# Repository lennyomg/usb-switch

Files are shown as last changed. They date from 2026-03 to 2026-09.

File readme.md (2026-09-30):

# USB Switch

This is a programmable USB 2.0 switch that connects one of two USB devices to a USB host at a time. It switches both data and power, fully disconnecting the inactive device. You can control it with a button or an external module.

This device is not a USB hub, neither logically nor internally. The switch is unidirectional: it cannot switch a single USB peripheral between two USB hosts.



### Technical details

The board is powered by an ATtiny1624, which controls FSUSB63UMX for switching USB data and TPS2066C for switching USB power. The board includes:
* 16 KB of storage, 2 KB of memory, and 256 bytes of EEPROM
* a 3.3 V regulator with a maximum current of 250 mA
* a USB-to-serial converter
* a single accessible LED
* two non-accessible LEDs for power status
* a built-in push button with an external 2.54 mm header
* a piezo speaker
* 2.54 mm header with 3.3 V, GND, and four GPIO/SPI pins

Check the [assembly guide](ASSEMBLY-GUIDE.md) and [dev notes](DEV-NOTES.md) for more details. Gerber files, BOM, STLs, and schematics can be found in [releases](https://github.com/lennyomg/usb-switch/releases/latest).

The `src` folder contains firmware examples built with PlatformIO.

### Application

This is primarily designed as a wired or wireless remote control for USB switching. For example, I added an external [433MHz radio garage door opener receiver](https://www.amazon.com/dp/B09P89RF8R) module and now I can switch between two wireless CarPlay adapters using my car HomeLink garage opener button.



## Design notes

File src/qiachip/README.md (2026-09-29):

This sample uses the built-in button or any of the four extension inputs to select the USB port. Each button press or rising signal on an extension input switches between port 1 and port 2. The selected port is saved to EEPROM and restored on startup. The buzzer plays a different tune for each selected port. The extension pins are connected to the [QIACHIP](https://www.amazon.com/dp/B09P89RF8R) RF module.

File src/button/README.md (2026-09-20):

This sample uses a momentary push button connected to the button input to select the USB port. Each press switches between port 1 and port 2. The selected port is saved to EEPROM and restored on startup. The sample also works with a wired push button.

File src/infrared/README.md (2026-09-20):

This sample uses an [Adafruit IR receiver](https://www.adafruit.com/product/5990) connected to PA1 to select a USB port with a generic remote. To learn a remote button, first select a port with the built-in button. Then hold the built-in button and press the button on the remote. The LED indicates IR reception. The selected port is saved to EEPROM and restored on startup.

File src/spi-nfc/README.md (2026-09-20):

This sample uses a PN532 NFC reader over SPI to select a USB port with a tag UID. Connect MOSI to PA1, MISO to PA2, SCK to PA3, and CS to PA4. To learn a tag, first select a port with the built-in button. Then hold the button and present the tag to the reader. The LED blinks three times when you release the button after learning. The selected port is saved to EEPROM and restored on startup.

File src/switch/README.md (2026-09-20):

This sample uses an external latching switch connected to the button input to select the USB port. A closed switch selects port 1; an open switch selects port 2.

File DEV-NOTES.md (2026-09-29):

# DEV NOTES

## Firmware

* Firmware source code is for Platform IO.

* Follow the assembly guide to install USB drivers. Update `upload_port` in `platformio.ini` accordingly.

* Set the switch to the ON-ON position to force the board into development mode and activate the built-in USB programmer.

* Firmware must guarantee that only one output is enabled at a time.

* `PIN_USB_PWR_1` and `PIN_USB_PWR_2` are intentionally swapped to compensate for the corresponding swap on the board.

* Some USB hosts may briefly cut off power when the board turns off both outputs. Therefore, save any persistent state before switching outputs.

* Each EEPROM cell has a limited write endurance (approximately 100,000 cycles), so depending on usage, consider rotating addresses used for stored data.

* On switching, disconnect data before disabling VBUS. When enabling a port, enable VBUS first and connect data after VBUS has stabilized. Keep the pre-connect powered interval below 100 ms.

* Set pins PA1, PA2, PA3, and PA4 to `INPUT_PULLUP` mode unless they are used by an external IC.

* The firmware must be configured for 10 MHz and internal oscillator.

## Board

* FSUSB63UMX is a 3:1 USB multiplexer. Outputs 1 and 2 are wired to USB ports and controlled by firmware. Output 3 is connected to CH340 programmer and selected by the slide switch.

* TPS2066C controls USB power switching.

* ATtiny controls data and power switching.

* Switched VBUS outputs are wired to green power-status LEDs. TPS2066C prevents OUT-to-IN current, but LEDs will be powered if voltage is applied to a USB output port.

* Logical data and power net numbers do not match physical port numbers because of the different pin order.

* The USB-C connection has 5.1 kΩ resistors and SMF5V0A TVS surge protection.

* USB input data lines cross each other on different layers because of FSUSB63UMX's pin order. The number of vias on each data line must match, and traces within each USB differential pair should be closely length-matched.

* Each USB input and output has a USBLC6. USBLC6 is a flow-through ESD protection device, meaning that pins 1-6 and 3-4 are connected internally. The board's custom USBLC6 footprints include jumpers that connect these pin pairs, although directly shorting each pair also works.

* Setting 218-2LPST slide switch to the ON-ON position forces FSUSB63UMX to activate CH340X UPDI programmer. The UPDI pin is reserved exclusively for programming and must not be reused as GPIO. It is connected to CH340X programming interface and exposed as a troubleshooting test point. Do not apply 12 V to this net, as doing so could damage CH340X.

* ATtiny controls a single red LED to indicate a user-defined state.

* ATtiny can be controlled by the active-low push button. The push button has a 2.54 mm pin header for connecting a wired external button. Because the wire may be long, a GSMF3.3A TVS diode, a current-limiting resistor, and an external pull-up are included to protect against noise and ESD. The two-pin 2.54 mm header is physically compatible with through-hole 2.00 mm and 2.50 mm JST connectors (confirmed).

* ATtiny can play a tune through a CPT-9019A-SMT-TR. It MUST be a piezoelectric transducer, NOT a magnetic buzzer. The selected transducer is compatible with `CUI_CPT-9019S-SMT` footprint (confirmed).

* 218-2LPST slide switch is compatible with Copal_CHS-02B footprint (confirmed).

* ATtiny pins PA1, PA2, PA3, and PA4 are connected to 2.54 mm headers to use as an SPI interface or GPIO.

* Two 47 µF 0805 capacitors per an output is a way to mitigate the recommended 120 µF (TPS2066C specs).

* The board has four layers: F.Cu for USB routing and SMD; In1.Cu for the GND plane; In2.Cu for power lines and the GND plane; and B.Cu for control lines.

* USB data trace dimensions target a 90 Ω differential impedance for the specified stackup: 0.25 mm width, 0.15 mm gap, and 0.75 mm clearance from the ground plane on the same layer.

* TPS channels should default to OFF during initial attachment. If the MCU immediately enables a channel, the upstream source will see both input and output capacitance. The TPS soft-start function might mitigate this, but it is better to avoid enabling a channel immediately.

* USB-C resistors must be 5.1 kΩ **±1%**.

* USB shields are connected to GND.

## Pre-order Validation

* Implementation notes above must not contradict themselves.

* Schematic and PCB should match the description.

* SPI header is correctly mapped to ATtiny's SPI hardware.

* Buzzer is connected to a PWM-capable pin.

* Final UPDI routing enables simple USB-to-ATtiny Arduino programming.

* Verify USB-C input TVS protection against the diode datasheet.

* Verify the external button TVS surge protection against the diode datasheet.

* USB-C routing must be valid for a USB-C peripheral device.

* Verify capacitor and resistor values and tolerances.

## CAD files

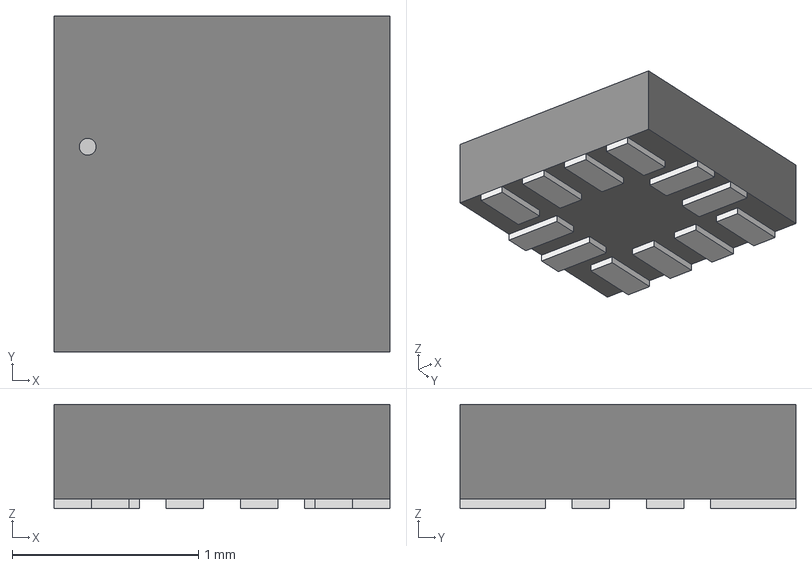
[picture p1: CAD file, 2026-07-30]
schematics/kvm/3d-models/UMLP12_1P8X1P8_ONS.step
1.80 x 1.80 x 0.561 mm

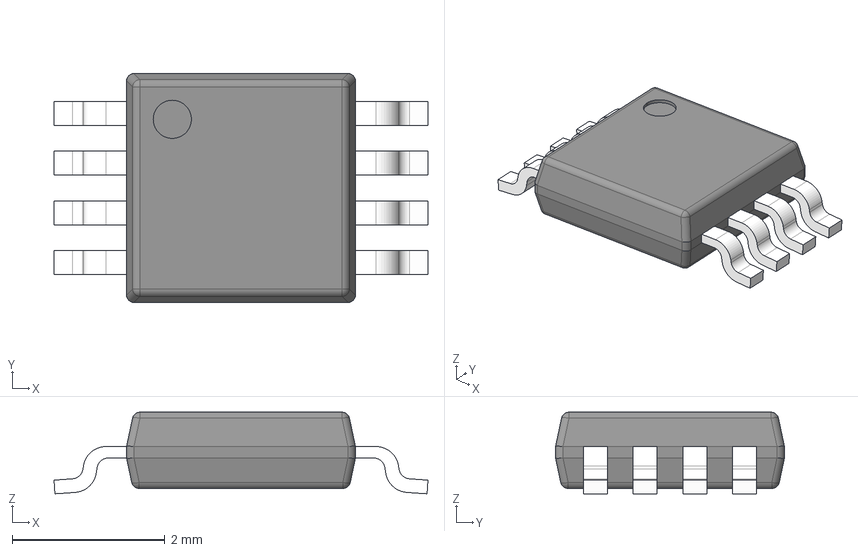
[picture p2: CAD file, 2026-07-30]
schematics/kvm/3d-models/DGN0008G.stp
4.90 x 3.00 x 1.07 mm
BODY-DGN0008G
LEAD-DGN0008G x 8
PIN1_DGN0008G
DAP_DGN0008G

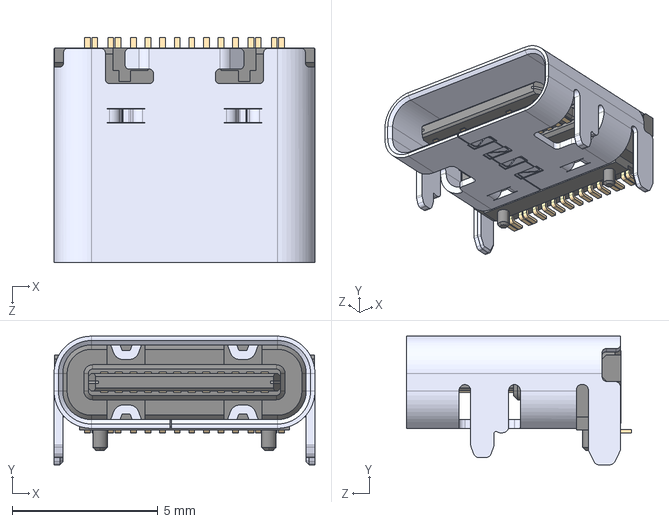
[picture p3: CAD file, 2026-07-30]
schematics/kvm/3d-models/USB4105-GF-A.STEP
8.94 x 4.41 x 7.71 mm

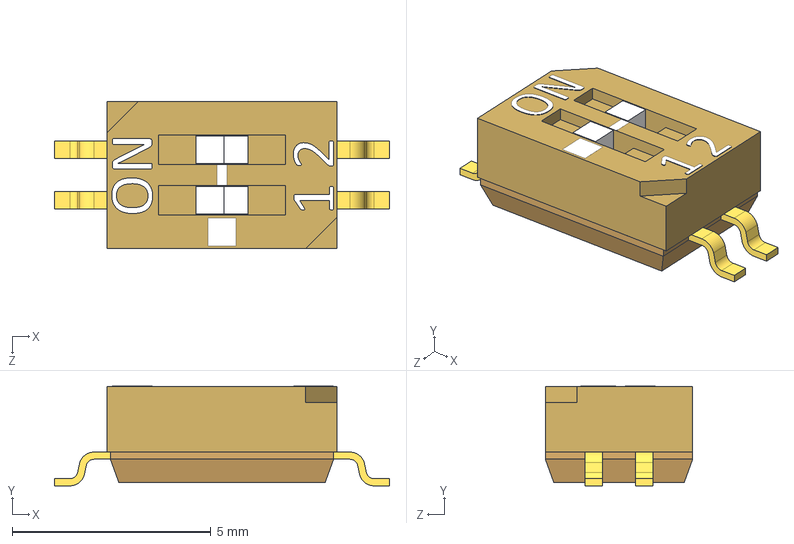
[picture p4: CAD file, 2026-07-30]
schematics/kvm/3d-models/218-2LP.STEP
8.43 x 2.51 x 3.71 mm
218 terminal lead frame x 2

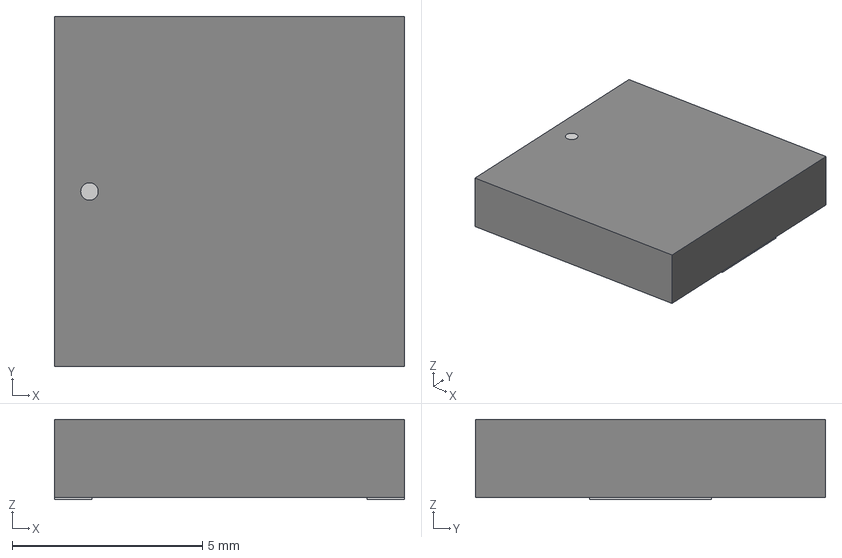
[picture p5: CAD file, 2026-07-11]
schematics/kvm/3d-models/CPT-9019A_CUD.step
9.19 x 9.19 x 2.11 mm

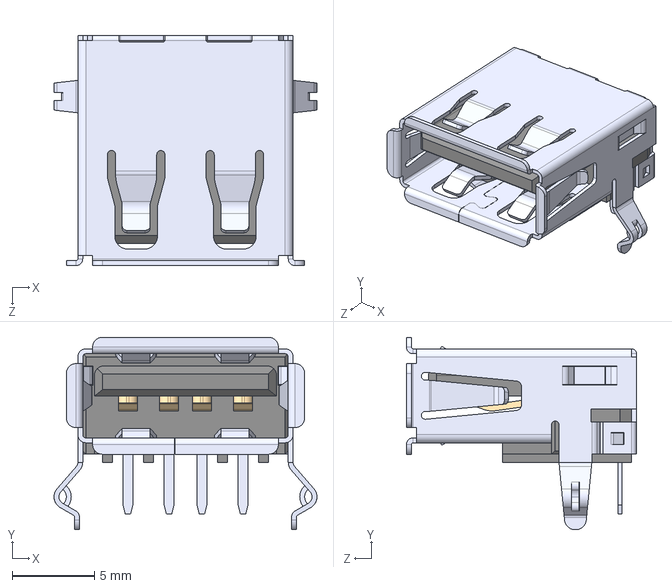
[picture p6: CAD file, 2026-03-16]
schematics/kvm/3d-models/SS-52100-001.STEP
16.0 x 11.7 x 14.0 mm

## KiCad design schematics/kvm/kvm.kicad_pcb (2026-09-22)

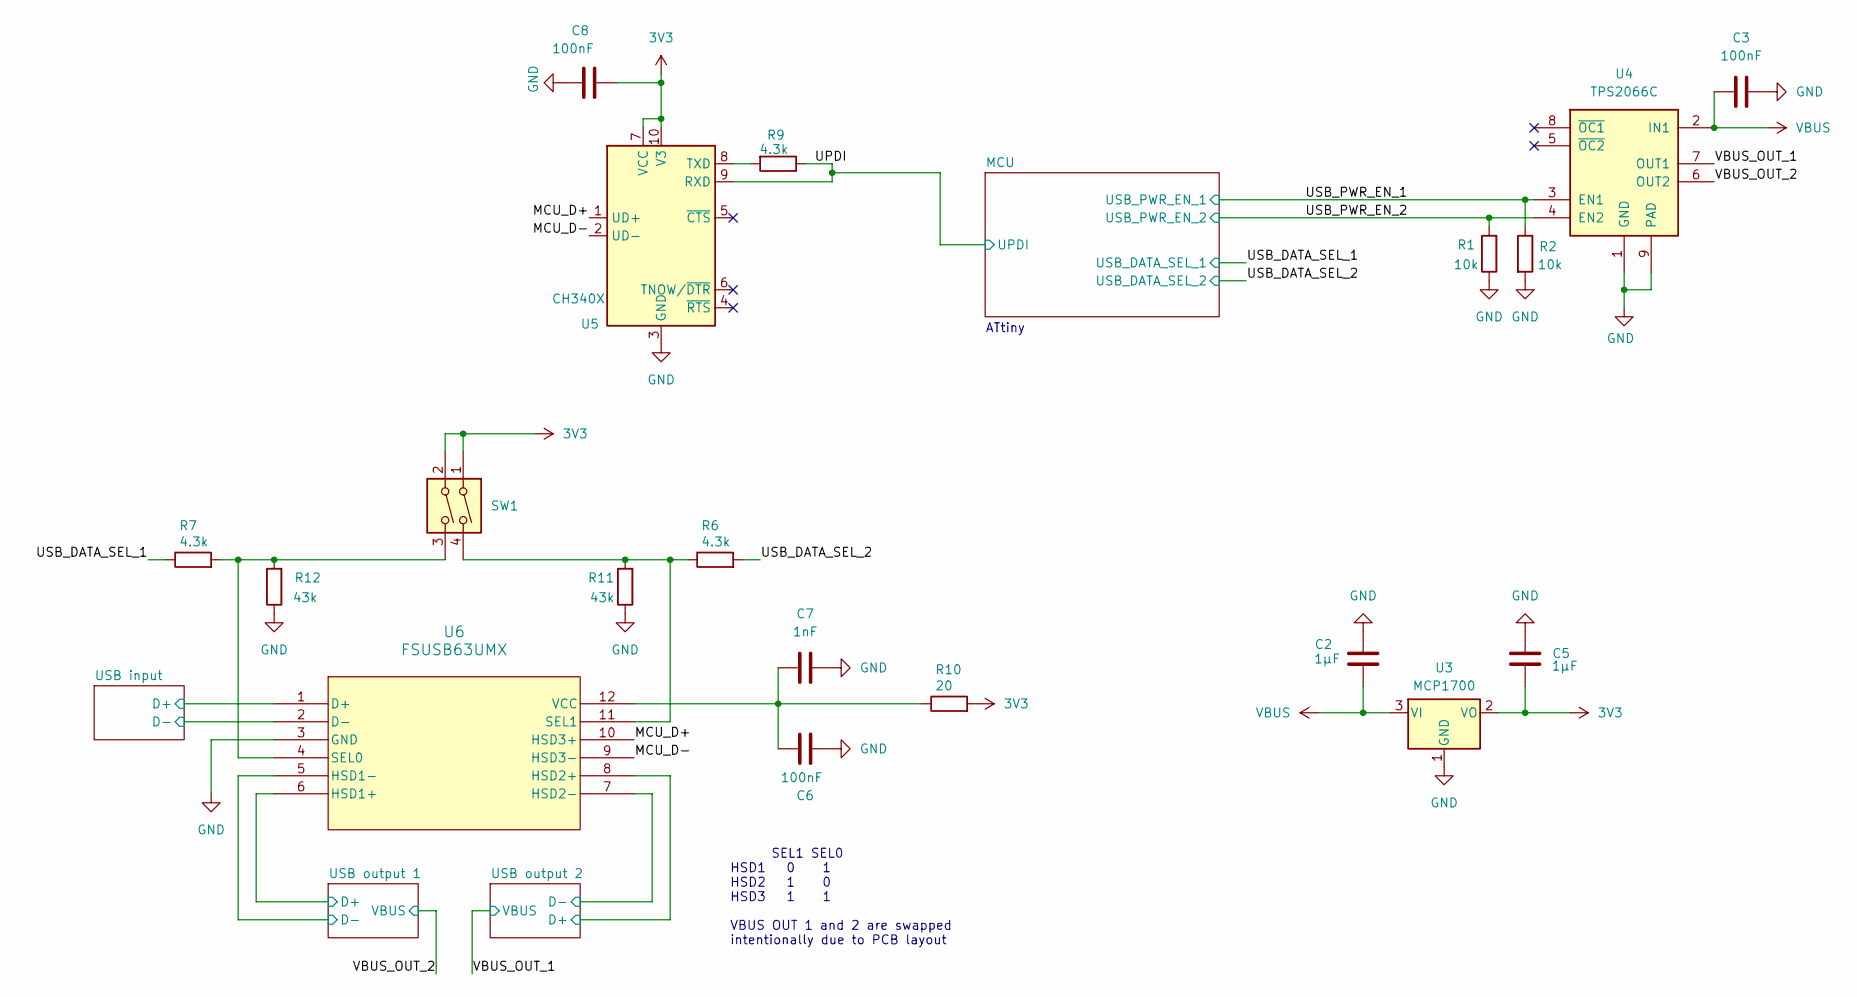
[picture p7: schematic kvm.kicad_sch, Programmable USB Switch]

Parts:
C2, C5: 1µF; C_0603_1608Metric
C3, C6, C8: 100nF; C_0603_1608Metric
C7: 1nF; C_0603_1608Metric
R1, R2: 10k; R_0603_1608Metric
R6, R7, R9: 4.3k; R_0603_1608Metric
R10: 20; R_0603_1608Metric
R11, R12: 43k; R_0603_1608Metric
SW1: SW_Slide_x2; SW_DIP_SPSTx02_Slide_Copal_CHS-02B_W7.62mm_P1.27mm; MPN 218-2LPST; DigiKey CT2182LPST-ND
U3: MCP1700; SOT-23; MPN MCP1700T-3302E/TT; DigiKey MCP1700T3302ETTCT-ND
U4: TPS2066C; HVSSOP-8-1EP_3x3mm_P0.65mm_EP1.57x1.89mm; MPN TPS2066CDGNR; DigiKey 296-39355-1-ND
U5: CH340X; MSOP-10_3x3mm_P0.5mm; MPN SMD IC CH340X; DigiKey 1188-SMDICCH340X-ND
U6: FSUSB63UMX; UMLP12_1P8X1P8_ONS_WIDE; MPN FSUSB63UMX; DigiKey FSUSB63UMXCT-ND

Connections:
3V3: C5.2, C8.1, R10.2, SW1.1, SW1.2, U3.2 (VO), U5.7 (VCC), U5.10 (V3); also elsewhere on the board
/MCU_D+: U5.1 (UD+), U6.10 (HSD3+)
/MCU_D-: U5.2 (UD-), U6.9 (HSD3-)
/UPDI: R9.1, U5.9 (RXD); also elsewhere on the board
/USB input/D+: U6.1 (D+); also elsewhere on the board
/USB input/D-: U6.2 (D-); also elsewhere on the board
/USB output 1/D+: U6.6 (HSD1+); also elsewhere on the board
/USB output 1/D-: U6.5 (HSD1-); also elsewhere on the board
/USB output 2/D+: U6.8 (HSD2+); also elsewhere on the board
/USB output 2/D-: U6.7 (HSD2-); also elsewhere on the board
/USB_DATA_SEL_1: R7.1; also elsewhere on the board
/USB_DATA_SEL_2: R6.2; also elsewhere on the board
/USB_PWR_EN_1: R2.1, U4.3 (EN1); also elsewhere on the board
/USB_PWR_EN_2: R1.2, U4.4 (EN2); also elsewhere on the board
/VBUS_OUT_1: U4.7 (OUT1); also elsewhere on the board
/VBUS_OUT_2: U4.6 (OUT2); also elsewhere on the board
GND: C2.2, C3.2, C5.1, C6.2, C7.2, C8.2, R1.1, R2.2, R11.1, R12.1, U3.1 (GND), U4.1 (GND), U4.9 (PAD), U5.3 (GND), U6.3 (GND); also elsewhere on the board
unnamed: R9.2, U5.8 (TXD)
unnamed: R7.2, R12.2, SW1.3, U6.4 (SEL0)
unnamed: R6.1, R11.2, SW1.4, U6.11 (SEL1)
unnamed: C6.1, C7.1, R10.1, U6.12 (VCC)
VBUS: C2.1, C3.1, U3.3 (VI), U4.2 (IN1); also elsewhere on the board

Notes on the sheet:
VBUS OUT 1 and 2 are swapped intentionally due to PCB layout
ATtiny
SEL1 SEL0 HSD1 0 1 HSD2 1 0 HSD3 1 1

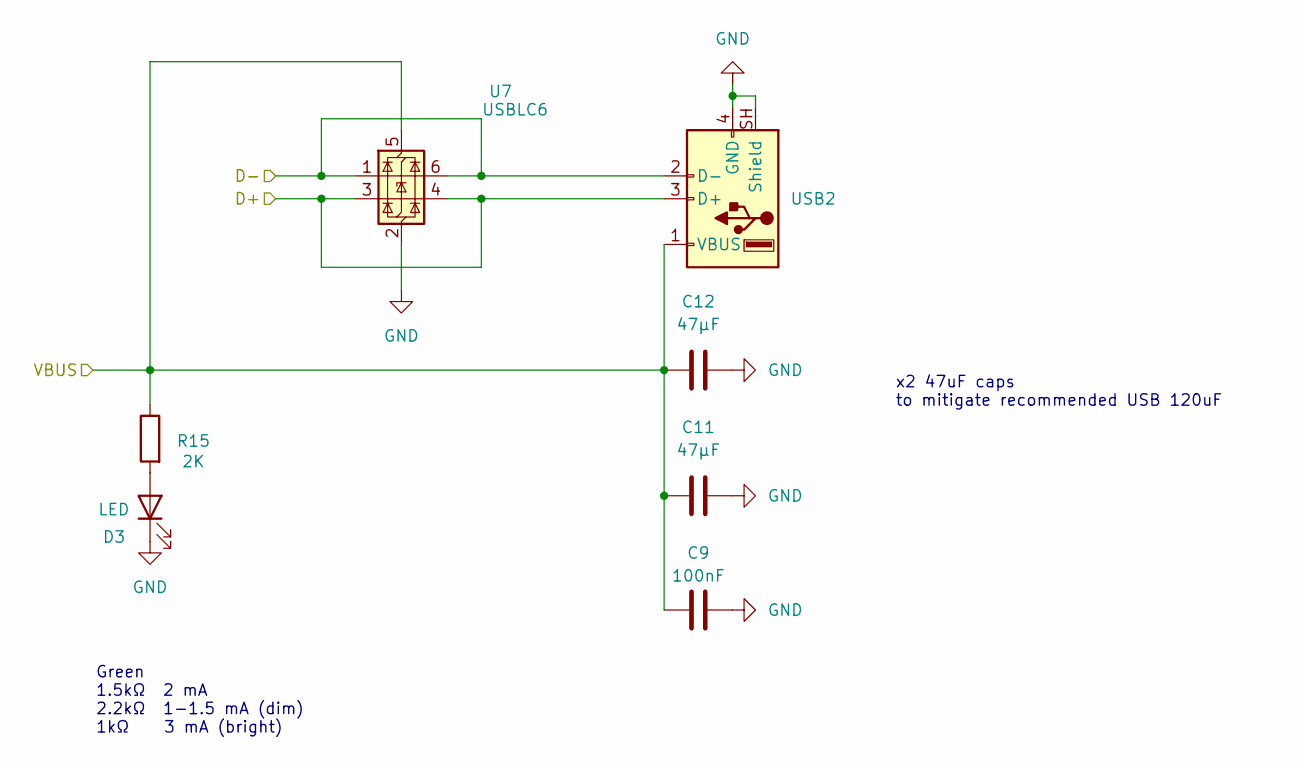
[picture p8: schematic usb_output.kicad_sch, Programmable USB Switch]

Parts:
C9: 100nF; C_0603_1608Metric
C11, C12: 47µF; C_0805_2012Metric
D3: LED; LED_0805_2012Metric; MPN 150080VS75000; DigiKey 732-4986-1-ND
R15: 2K; R_0603_1608Metric
U7: USBLC6; USBLC6-2SC6_SOT-23-6; MPN USBLC6-2SC6; DigiKey 497-5235-1-ND
USB2: USB; USB_A_Stewart_SS-52100-001_Horizontal; MPN SS-52100-001; DigiKey SS-52100-001

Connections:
/USB output 1/D+: U7.3 (I/O2), U7.4 (I/O2), USB2.3 (D+); also elsewhere on the board
/USB output 1/D-: U7.1 (I/O1), U7.6 (I/O1), USB2.2 (D-); also elsewhere on the board
/VBUS_OUT_2: C9.1, C11.1, C12.1, R15.1, U7.5 (VBUS), USB2.1 (VBUS); also elsewhere on the board
GND: C9.2, C11.2, C12.2, D3.1 (K), U7.2 (GND), USB2.4 (GND), USB2.SH (Shield); also elsewhere on the board
unnamed: D3.2 (A), R15.2

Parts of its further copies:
C10: 100nF; C_0603_1608Metric
C13, C14: 47µF; C_0805_2012Metric
D5: LED; LED_0805_2012Metric; MPN 150080VS75000; DigiKey 732-4986-1-ND
R16: 2K; R_0603_1608Metric
U8: USBLC6; USBLC6-2SC6_SOT-23-6; MPN USBLC6-2SC6; DigiKey 497-5235-1-ND
USB3: USB; USB_A_Stewart_SS-52100-001_Horizontal; MPN SS-52100-001; DigiKey SS-52100-001

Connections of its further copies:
/USB output 2/D+: U8.3 (I/O2), U8.4 (I/O2), USB3.3 (D+); also elsewhere on the board
/USB output 2/D-: U8.1 (I/O1), U8.6 (I/O1), USB3.2 (D-); also elsewhere on the board
/VBUS_OUT_1: C10.1, C13.1, C14.1, R16.1, U8.5 (VBUS), USB3.1 (VBUS); also elsewhere on the board
GND: C10.2, C13.2, C14.2, D5.1 (K), U8.2 (GND), USB3.4 (GND), USB3.SH (Shield); also elsewhere on the board
unnamed: D5.2 (A), R16.2

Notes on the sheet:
x2 47uF caps to mitigate recommended USB 120uF
Green 1.5kΩ 2 mA 2.2kΩ 1-1.5 mA (dim) 1kΩ 3 mA (bright)

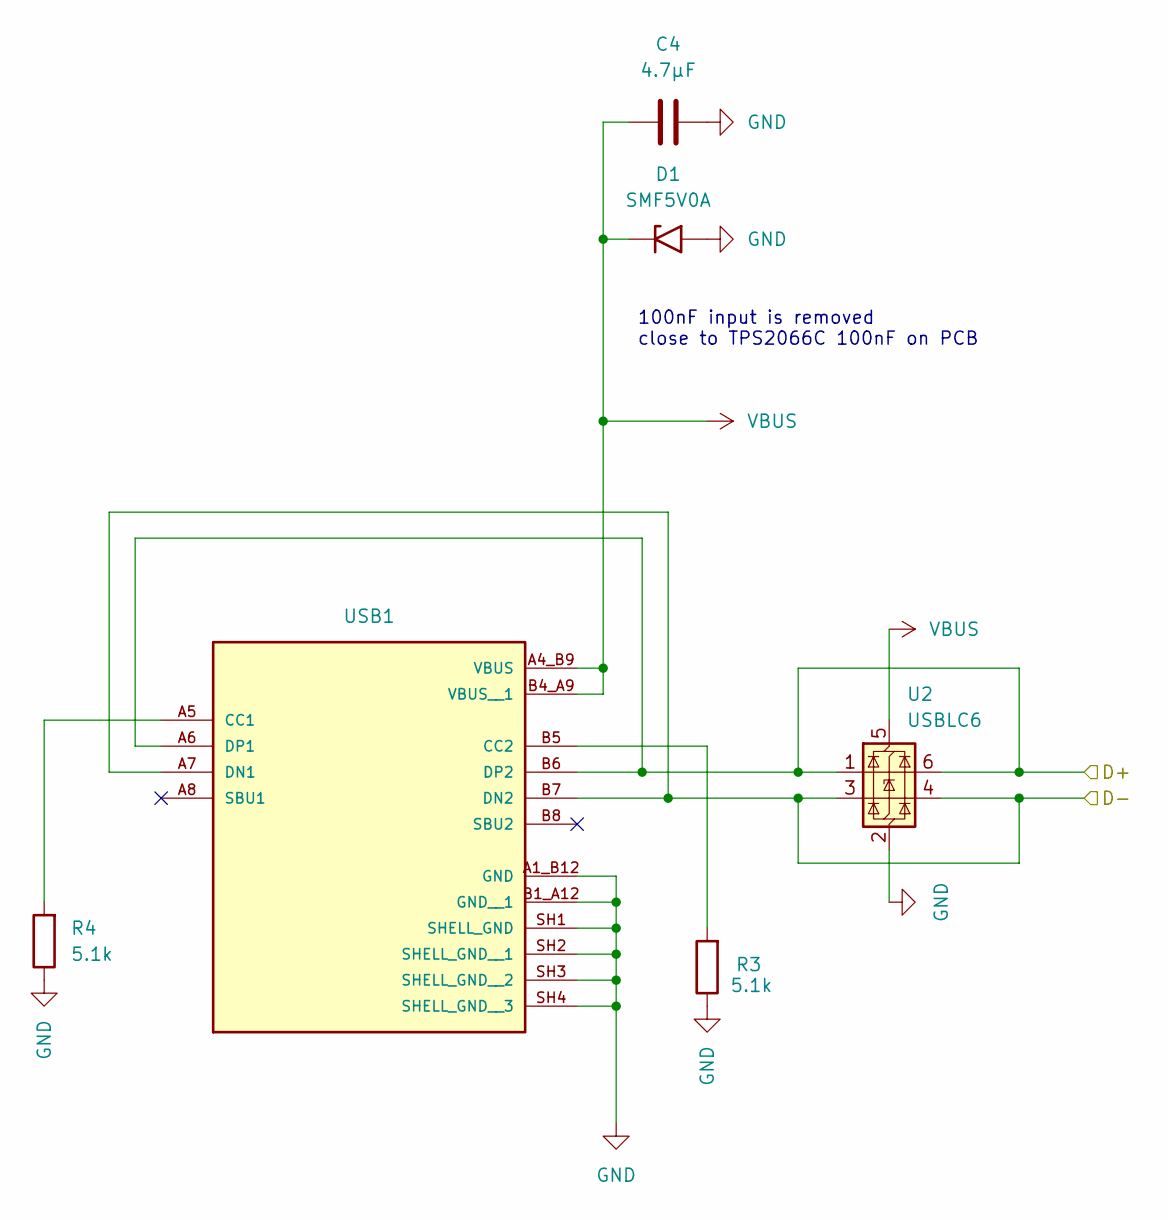
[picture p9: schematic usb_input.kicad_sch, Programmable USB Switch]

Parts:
C4: 4.7µF; C_0603_1608Metric
D1: SMF5V0A; D_SMF; MPN SMF5V0A-E3-08; DigiKey SMF5V0A-E3-08CT-ND
R3, R4: 5.1k; R_0603_1608Metric
U2: USBLC6; USBLC6-2SC6_SOT-23-6; MPN USBLC6-2SC6; DigiKey 497-5235-1-ND
USB1: USB_C_Receptacle_USB2.0_14P; GCT_USB4105-GF-A; MPN USB4105-GF-A; DigiKey 2073-USB4105-GF-ACT-ND

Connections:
/USB input/D+: U2.1 (I/O1), U2.6 (I/O1), USB1.A6 (DP1), USB1.B6 (DP2); also elsewhere on the board
/USB input/D-: U2.3 (I/O2), U2.4 (I/O2), USB1.A7 (DN1), USB1.B7 (DN2); also elsewhere on the board
GND: C4.2, D1.2 (A2), R3.1, R4.1, U2.2 (GND), USB1.A1_B12 (GND), USB1.B1_A12 (GND__1), USB1.SH1 (SHELL_GND), USB1.SH2 (SHELL_GND__1), USB1.SH3 (SHELL_GND__2), USB1.SH4 (SHELL_GND__3); also elsewhere on the board
unnamed: R4.2, USB1.A5 (CC1)
unnamed: R3.2, USB1.B5 (CC2)
VBUS: C4.1, D1.1 (A1), U2.5 (VBUS), USB1.A4_B9 (VBUS), USB1.B4_A9 (VBUS__1); also elsewhere on the board

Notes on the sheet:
100nF input is removed close to TPS2066C 100nF on PCB

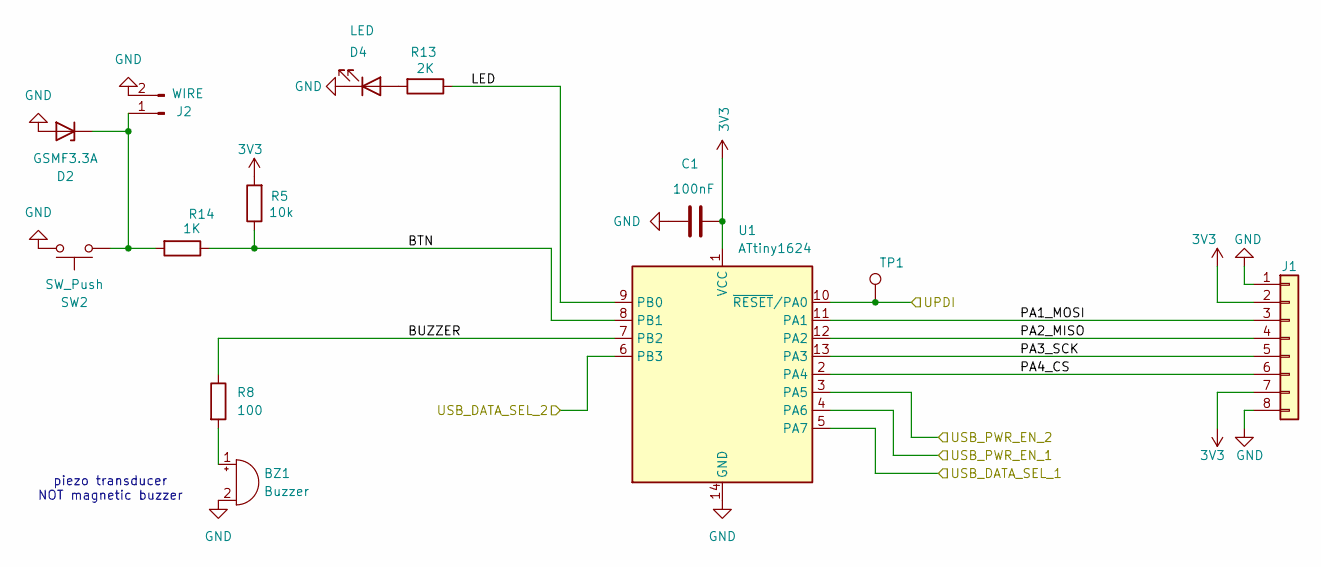
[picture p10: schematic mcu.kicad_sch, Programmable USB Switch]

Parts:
BZ1: Buzzer; Buzzer_CUI_CPT-9019S-SMT; MPN CPT-9019A-SMT-TR; DigiKey 2223-CPT-9019A-SMT-TRCT-ND
C1: 100nF; C_0603_1608Metric
D2: GSMF3.3A; D_SOD-123FL_GSMF3-3A; MPN GSMF3.3A; DigiKey 4786-GSMF3.3ACT-ND
D4: LED; LED_0805_2012Metric; MPN 150080SS75000; DigiKey 732-4985-1-ND
J1: EXT; PinHeader_1x08_P2.54mm_Vertical
J2: WIRE; PinHeader_1x02_P2.54mm_Vertical
R5: 10k; R_0603_1608Metric
R8: 100; R_0603_1608Metric
R13: 2K; R_0603_1608Metric
R14: 1K; R_0603_1608Metric
SW2: SW_Push; SW_PUSH_6mm; MPN TS02-66-43-BK-160-LCR-D; DigiKey 2223-TS02-66-43-BK-160-LCR-D-ND
TP1: TestPoint; TestPoint_Pad_D1.5mm
U1: ATtiny1624; TSSOP-14_4.4x5mm_P0.65mm; MPN ATTINY1624-XUR; DigiKey 150-ATTINY1624-XURCT-ND

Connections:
3V3: C1.1, J1.2, J1.7, R5.2, U1.1 (VCC); also elsewhere on the board
/MCU/BTN: R5.1, R14.1, U1.8 (PB1)
/MCU/BUZZER: R8.1, U1.7 (PB2)
/MCU/LED: R13.1, U1.9 (PB0)
/MCU/PA1_MOSI: J1.3, U1.11 (PA1)
/MCU/PA2_MISO: J1.4, U1.12 (PA2)
/MCU/PA3_SCK: J1.5, U1.13 (PA3)
/MCU/PA4_CS: J1.6, U1.2 (PA4)
/UPDI: TP1.1 (1_1), U1.10 (~RESET/PA0); also elsewhere on the board
/USB_DATA_SEL_1: U1.5 (PA7); also elsewhere on the board
/USB_DATA_SEL_2: U1.6 (PB3); also elsewhere on the board
/USB_PWR_EN_1: U1.4 (PA6); also elsewhere on the board
/USB_PWR_EN_2: U1.3 (PA5); also elsewhere on the board
GND: BZ1.2 (-), C1.2, D2.2 (A), D4.1 (K), J1.1, J1.8, J2.2, SW2.2, U1.14 (GND); also elsewhere on the board
unnamed: BZ1.1 (+), R8.2
unnamed: D2.1 (K), J2.1, R14.2, SW2.1
unnamed: D4.2 (A), R13.2

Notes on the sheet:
piezo transducer NOT magnetic buzzer

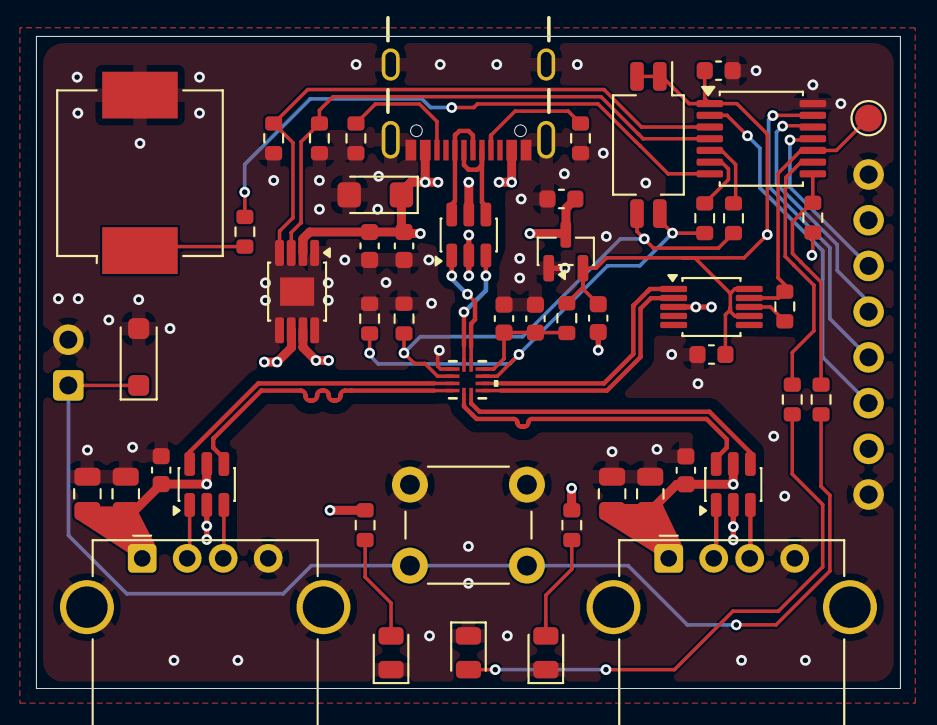
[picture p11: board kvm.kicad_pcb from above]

Board: 4 copper layers, 48.0 x 36.2 mm, 52 parts (0 on the bottom side), 36 nets.

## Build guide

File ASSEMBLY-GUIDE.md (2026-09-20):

# Assembly guide

This is how to build, print, flash, and assemble this project. Check [releases](https://github.com/lennyomg/usb-switch/releases/latest) for manufacturing files.

## Board

Order a 4-layer PCB using the attached Gerber and drill files. Add a stencil to your order if possible. A rework station or hot plate is required to assemble the board, the USB mux is too small for a soldering iron.

The BOM contains manufacturer part numbers for DigiKey and LCSC. When ordering parts, pay attention to the specified tolerances (5.1 kΩ **±1%** resistors, for example).

### Enclosure

[Project in OnShape](https://cad.onshape.com/documents/5c8a980f8b2f233ca52af940/w/8f21e194ecc758069b76b15f/e/5b9ec8950a9bfdcf718e2e62).

The project has configuration parameters to increase the box width and height. It also has options to hide the button, speaker holes, and LEDs.

Print in regular PETG with a **0.2 mm** nozzle, preferably in a dark color. Cut small pieces of translucent PETG filament and insert them into the LED holes to make light diffusers. Screw the top and bottom parts together with four M2 screws.

## USB serial driver

The board includes CH340 USB-to-serial converter for programming. Set the onboard switch to the **ON-ON** position, disconnect all devices from the USB-A outputs, and connect the board's USB-C input to the computer.

##### macOS

Install the WCH driver with Homebrew:

```sh
brew install --cask wch-ch34x-usb-serial-driver
```

Follow any prompt to allow the driver in **System Settings > Privacy & Security**. Restart the computer if requested, reconnect the board, and run `ls /dev/cu.*` again. Look for a device such as `/dev/cu.wchusbserial1420` or `/dev/cu.usbserial-1420`.

##### Windows

Windows may install the CH340 driver automatically. To find the port, open **Device Manager > Ports (COM & LPT)**, look for **USB-SERIAL CH340**, and note its port, such as `COM7`.

If the device is missing or appears with a warning icon, download and install the official [WCH CH340/CH341 Windows driver](https://www.wch-ic.com/downloads/CH341SER_ZIP.html). 

## Install AVRDUDE

Use AVRDUDE 8 or newer for flashing the device.

##### macOS

Install AVRDUDE with Homebrew:

```sh
brew install avrdude
```

##### Windows

1. Download the latest Windows x64 ZIP archive from the official [AVRDUDE releases page](https://github.com/avrdudes/avrdude/releases/latest).
2. Extract the archive to a permanent folder.
3. Add that folder to `PATH`, or open PowerShell in the extracted folder and run `avrdude.exe` from there.

## Flash the board

Replace the example serial port and `file.hex` with the actual port and firmware file path.

##### macOS

```sh
avrdude -c serialupdi -p t1624 -P /dev/cu.wchusbserial1420 -b 115200 -U flash:w:file.hex:i
```

##### Windows

```powershell
.\avrdude.exe -c serialupdi -p t1624 -P COM7 -b 115200 -U flash:w:file.hex:i
```

Wait for AVRDUDE to report that verification succeeded. Disconnect the USB-C cable, set the onboard switch to the **1-2** position, and reconnect the board.

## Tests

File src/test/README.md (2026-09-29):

This firmware is used to test an assembled board. On startup, the LED flashes five times and the buzzer plays three tones. Extension input 1 turns both USB ports off, input 2 selects port 1, and input 3 selects port 2. The built-in button or extension input 4 switches between ports 1 and 2. Each action plays a tone, and the LED remains on while both ports are off.

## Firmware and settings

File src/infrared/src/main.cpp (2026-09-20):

// Copyright (c) 2026 Leonid R.
// SPDX-License-Identifier: MIT

#include <Arduino.h>
#include <Bounce2.h>
#include <EEPROM.h>
#define IR_USE_AVR_TIMER_A
#include <IRremote.hpp>

constexpr auto PIN_USB_PWR_1 = PIN_PA6;
constexpr auto PIN_USB_PWR_2 = PIN_PA5;
constexpr auto PIN_USB_DAT_1 = PIN_PB3;
constexpr auto PIN_USB_DAT_2 = PIN_PA7;
constexpr auto PIN_BUZZER = PIN_PB2;
constexpr auto PIN_BTN = PIN_PB1;
constexpr auto PIN_LED = PIN_PB0;
constexpr auto PIN_IR = PIN_PA1;

constexpr uint8_t STATE_ADDR = 2;
constexpr uint8_t STATE_HEADER_1 = 0x55;
constexpr uint8_t STATE_HEADER_2 = 0xFF;
constexpr uint8_t STATE_1_LENGTH_ADDR = 3;
constexpr uint8_t STATE_2_LENGTH_ADDR = 4;
constexpr uint8_t STATE_1_DATA_ADDR = 10;
constexpr uint8_t STATE_2_DATA_ADDR = 100;

uint8_t state;
Bounce2::Button btn;
uint8_t data[4];
uint8_t dataLength;
bool learning = false;

void switchModeOff();
void switchMode1();
void switchMode2();
void ledOn();
void ledOff();
void readState();
void writeState();
bool readData();
bool matchData(uint8_t lengthAddr, uint8_t dataAddr);
void learnData(uint8_t learnAddr, uint8_t dataAddr);

void setup()
{
    pinMode(PIN_LED, OUTPUT);
    ledOff();

    switchModeOff();
    pinMode(PIN_USB_PWR_1, OUTPUT);
    pinMode(PIN_USB_PWR_2, OUTPUT);
    pinMode(PIN_USB_DAT_1, OUTPUT);
    pinMode(PIN_USB_DAT_2, OUTPUT);

    pinMode(PIN_BUZZER, OUTPUT);
    digitalWrite(PIN_BUZZER, LOW);

    pinMode(PIN_PA2, INPUT_PULLUP);
    pinMode(PIN_PA3, INPUT_PULLUP);
    pinMode(PIN_PA4, INPUT_PULLUP);

    btn.attach(PIN_BTN, INPUT_PULLUP);
    btn.interval(5);
    btn.setPressedState(LOW);

    if (EEPROM.read(0) != STATE_HEADER_1 || EEPROM.read(1) != STATE_HEADER_2)
    {
        EEPROM.write(0, STATE_HEADER_1);
        EEPROM.write(1, STATE_HEADER_2);
        EEPROM.write(STATE_ADDR, 1);
        for (auto addr = 3; addr < EEPROM.length(); addr++)
            EEPROM.write(addr, 0);
    }

    readState();
    switch (state)
    {
    case 1:
        switchMode1();
        break;
    case 2:
        switchMode2();
        break;
    }

    IrReceiver.begin(PIN_IR, ENABLE_LED_FEEDBACK, PIN_LED);
}

void loop()
{
    auto needSwitch = false;
    btn.update();

    if (IrReceiver.decode())
    {
        if (readData())
        {
            if (btn.isPressed() && !learning)
            {
                learning = true;
                switch (state)
                {
                case 1:
                    learnData(STATE_1_LENGTH_ADDR, STATE_1_DATA_ADDR);
                    break;
                case 2:
                    learnData(STATE_2_LENGTH_ADDR, STATE_2_DATA_ADDR);
                    break;
                }
            }
            else
            {
                if (matchData(STATE_1_LENGTH_ADDR, STATE_1_DATA_ADDR))
                {
                    if (state != 1)
                        needSwitch = true;
                }
                else if (matchData(STATE_2_LENGTH_ADDR, STATE_2_DATA_ADDR))
                {
                    if (state != 2)
                        needSwitch = true;
                }
            }
        }

        IrReceiver.resume();
    }

    if (btn.released())
    {
        if (!learning)
        {
            needSwitch = true;
        }
        else
        {
            learning = false;
        }
    }

    if (needSwitch)
    {
        switch (state)
        {
        case 2:
            state = 1;
            writeState();
            switchMode1();
            break;
        default:
            state = 2;
            writeState();
            switchMode2();
            break;
        }
    }
}

void switchModeOff()
{
    digitalWrite(PIN_USB_DAT_1, LOW);
    digitalWrite(PIN_USB_DAT_2, LOW);
    digitalWrite(PIN_USB_PWR_1, LOW);
    digitalWrite(PIN_USB_PWR_2, LOW);
}

void switchMode1()
{
    switchModeOff();
    delay(200);

    digitalWrite(PIN_USB_PWR_1, HIGH);
    delay(20);
    digitalWrite(PIN_USB_DAT_1, HIGH);
}

void switchMode2()
{
    switchModeOff();
    delay(200);

    digitalWrite(PIN_USB_PWR_2, HIGH);
    delay(20);
    digitalWrite(PIN_USB_DAT_2, HIGH);
}

void readState()
{
    state = EEPROM.read(STATE_ADDR);
}

void writeState()
{
    EEPROM.write(STATE_ADDR, state);
}

bool readData()
{
    const auto &code = IrReceiver.decodedIRData;

    if (code.flags & IRDATA_FLAGS_IS_REPEAT)
        return false;

    if (code.flags & IRDATA_FLAGS_WAS_OVERFLOW)
        return false;

    if (code.numberOfBits == 0)
        return false;

    if (code.numberOfBits > 32)
        return false;

    dataLength = (code.numberOfBits + 7) / 8;
    for (uint8_t i = 0; i < dataLength; i++)
        data[i] = (code.decodedRawData >> (8 * i)) & 0xFF;

    return true;
}

bool matchData(uint8_t lengthAddr, uint8_t dataAddr)
{
    if (EEPROM.read(lengthAddr) != dataLength)
        return false;

    for (uint8_t i = 0; i < dataLength; i++)
    {
        if (EEPROM.read(dataAddr + i) != data[i])
            return false;
    }

    return true;
}

void learnData(uint8_t learnAddr, uint8_t dataAddr)
{
    EEPROM.write(learnAddr, dataLength);
    for (uint8_t i = 0; i < dataLength; i++)
        EEPROM.write(dataAddr + i, data[i]);

    disableLEDFeedback();
    for (uint8_t i = 0; i < 3; i++)
    {
        ledOn();
        delay(150);
        ledOff();
        delay(150);
    }
    enableLEDFeedback();
}

void ledOn()
{
    digitalWrite(PIN_LED, HIGH);
}

void ledOff()
{
    digitalWrite(PIN_LED, LOW);
}

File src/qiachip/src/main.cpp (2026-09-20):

// Copyright (c) 2026 Leonid R.
// SPDX-License-Identifier: MIT

#include <Arduino.h>
#include <Bounce2.h>
#include <EEPROM.h>

constexpr auto PIN_USB_PWR_1 = PIN_PA6;
constexpr auto PIN_USB_PWR_2 = PIN_PA5;
constexpr auto PIN_USB_DAT_1 = PIN_PB3;
constexpr auto PIN_USB_DAT_2 = PIN_PA7;
constexpr auto PIN_BUZZER = PIN_PB2;
constexpr auto PIN_BTN = PIN_PB1;
constexpr auto PIN_LED = PIN_PB0;

constexpr auto PIN_EXT_1 = PIN_PA1; // hardware SPI MOSI
constexpr auto PIN_EXT_2 = PIN_PA2; // hardware SPI MISO
constexpr auto PIN_EXT_3 = PIN_PA3; // hardware SPI SCK
constexpr auto PIN_EXT_4 = PIN_PA4;
constexpr auto PIN_CS = PIN_PA4;

constexpr uint8_t STATE_ADDR = 0;

uint8_t state;
Bounce2::Button btn;
Bounce2::Button ext[4];

void switchModeOff();
void switchMode1();
void switchMode2();
void ledOn();
void ledOff();
void beep(unsigned int freq, unsigned long dur);
void readState();
void writeState();

void setup()
{
    pinMode(PIN_LED, OUTPUT);
    ledOff();

    switchModeOff();
    pinMode(PIN_USB_PWR_1, OUTPUT);
    pinMode(PIN_USB_PWR_2, OUTPUT);
    pinMode(PIN_USB_DAT_1, OUTPUT);
    pinMode(PIN_USB_DAT_2, OUTPUT);

    pinMode(PIN_BUZZER, OUTPUT);
    digitalWrite(PIN_BUZZER, LOW);

    btn.attach(PIN_BTN, INPUT_PULLUP);
    btn.interval(5);
    btn.setPressedState(LOW);

    ext[0].attach(PIN_EXT_1, INPUT);
    ext[1].attach(PIN_EXT_2, INPUT);
    ext[2].attach(PIN_EXT_3, INPUT);
    ext[3].attach(PIN_EXT_4, INPUT);
    for (auto &e : ext)
    {
        e.interval(5);
        e.setPressedState(HIGH);
    }

    for (size_t i = 0; i < 5; i++)
    {
       delay(150);
       ledOff();
       delay(150);
       ledOn();
    }

    readState();

    switch (state)
    {
    case 1:
        switchMode1();
        break;
    case 2:
        switchMode2();
        break;
    }
}

void loop()
{
    btn.update();

    ext[0].update();
    ext[1].update();
    ext[2].update();
    ext[3].update();

    auto pressed =
        btn.pressed() ||
        ext[0].pressed() ||
        ext[1].pressed() ||
        ext[2].pressed() ||
        ext[3].pressed();

    if (pressed)
    {
        switch (state)
        {
        case 2:
            state = 1;
            writeState();
            switchMode1();
            break;
        default:
            state = 2;
            writeState();
            switchMode2();
            break;
        }
    }
}

void switchModeOff()
{
    ledOn();

    digitalWrite(PIN_USB_DAT_1, LOW);
    digitalWrite(PIN_USB_DAT_2, LOW);
    digitalWrite(PIN_USB_PWR_1, LOW);
    digitalWrite(PIN_USB_PWR_2, LOW);
}

void switchMode1()
{
    switchModeOff();
    delay(200);

    digitalWrite(PIN_USB_PWR_1, HIGH);
    delay(20);
    digitalWrite(PIN_USB_DAT_1, HIGH);

    beep(660, 100);
    beep(440, 100);
    beep(660, 100);

    ledOff();
}

void switchMode2()
{
    switchModeOff();
    delay(200);
    
    digitalWrite(PIN_USB_PWR_2, HIGH);
    delay(20);
    digitalWrite(PIN_USB_DAT_2, HIGH);

    beep(440, 150);
    beep(660, 150);

    ledOff();
}

void beep(const unsigned int freq, const unsigned long dur)
{
    tone(PIN_BUZZER, freq);
    delay(dur);
    noTone(PIN_BUZZER);
    digitalWrite(PIN_BUZZER, LOW);
}

void readState()
{
    state = EEPROM.read(STATE_ADDR);
}

void writeState()
{
    EEPROM.write(STATE_ADDR, state);
}

void ledOn()
{
    digitalWrite(PIN_LED, HIGH);
}

void ledOff()
{
    digitalWrite(PIN_LED, LOW);
}

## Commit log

2026-02-26 first order
    [kvm-B_Cu.gbr, kvm-B_Mask.gbr, kvm-B_Paste.gbr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]
2026-03-16 added usb port and xiao 3d models
    [SS-52100-001.STEP, Seeed Studio XIAO RP2040 v26.step, kvm.kicad_pcb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]
2026-03-22 replaced R1 and R2 with 0ohm links; added digikey url for usb connectors
    [kvm.kicad_sch]
2026-03-22 removed old gerber files
    [kvm-B_Cu.gbr, kvm-B_Mask.gbr, kvm-B_Paste.gbr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]
2026-03-22 added files for 3d printing
    [board.step, shell_bottom.stl, shell_top.stl]
2026-04-03 readme and supporting files
    [kvm.kicad_sch]
2026-05-12 ignore missing NEOPIXEL_POWER pin
2026-07-11 revision 2: proper buzzer layout, extra external pins, optimized layout, button, optional wired button, compact
    [CPT-9019A_CUD.step, VSSOP-10_3x3mm_P0.5mm.step, board.step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]
2026-07-11 replaced ferrite beads with 0 ohm links due to power issues
    [kvm.kicad_pcb, kvm.kicad_sch]
2026-07-30 dev: board is ready
    [218-2LP.STEP, DGN0008G.stp, UMLP12_1P8X1P8_ONS.step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]
2026-08-10 rev3 ordered
    [kvm.kicad_pcb, kvm.kicad_sch, mcu.kicad_sch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]
2026-09-20 adruino samples
    [board.step, shell_bottom.stl, shell_top.stl]
2026-09-20 updated license information
    [kvm.kicad_pcb, kvm.kicad_sch, mcu.kicad_sch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]
2026-09-22 updated bom
    [kvm.kicad_pcb, mcu.kicad_sch]
2026-09-23 removed unused copied symbols and footprints
    [Seeed Studio XIAO RP2040 v26.step, VSSOP-10_3x3mm_P0.5mm.step]
2026-09-29 renamed sample project
2026-09-30 Update assembly guide with image and instructions
    Added an image and additional assembly instructions for the board.

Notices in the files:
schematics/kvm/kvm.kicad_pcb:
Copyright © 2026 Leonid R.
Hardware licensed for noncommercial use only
